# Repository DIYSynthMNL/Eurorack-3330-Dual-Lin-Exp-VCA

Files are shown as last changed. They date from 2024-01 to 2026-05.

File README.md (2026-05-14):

# Eurorack-3330-Dual-Lin-Exp-VCA

A Eurorack dual VCA based on the [AS3330](https://electricdruid.net/product/as3330-vca/) chip — two independent voltage-controlled amplifiers in one PDIP-18 package, each with simultaneous linear and exponential control inputs. Wide control range (120 dB), low distortion (<0.1%), low feedthrough (<−90 dB).

This design adds a **Lin/Exp blend knob per channel** (smooth pan between linear and exponential response), a **CV attenuator + offset** for shaping the control signal, an **LED level indicator**, and a **mix output** that sums both VCAs.

## Features

- **Two independent VCAs** in one chip (AS3330 PDIP-18)
- **Per-channel Lin/Exp blend** — one knob smoothly mixes linear and exponential CV response
- **CV attenuator + offset** per channel — handles ±5V, 0–5V, or 0–10V CV ranges
- **Mix output** (Sig 1 + Sig 2 summed via U5A/U5B)
- **Output-2 select jumper (JP1)** — Sig 2 jack outputs either VCA2 directly or the Mix
- **Bipolar LED indicator** per channel — shows CV level
- Eurorack ±12V power via either 16-pin IDC or 3-pin JST connector
- Local −5V reference rail (`-5VREF`) generated by a TL072-based reference for CV scaling

## Inputs and outputs

| Jack | Range | Notes |
|---|---|---|
| Sig In 1 | 10 Vpp (±5V) | Through 100K (Rl) to chip pin 4 IN1 |
| Sig In 2 | 10 Vpp (±5V) | Through 100K (Rl) to chip pin 13 IN2 |
| CV1 In | ±5V / 0–5V / 0–10V | Routed through CV scaling section (atten + offset + Lin/Exp blend) |
| CV2 In | ±5V / 0–5V / 0–10V | Same |
| Sig Out 1 | 10 Vpp (±5V) | Transimpedance buffer with R5 (100K) feedback |
| Sig Out 2 / Mix Out | 10 Vpp | JP1 selects between Sig Out 2 alone or the Mix Out (sum of both VCAs) |

Front-panel pots (per channel):

| Pot | Value | Function |
|---|---|---|
| RV1 / RV4 | 100K | **CV Attenuation** — scales the CV jack signal |
| RV3 / RV6 | 10K | **CV Offset** — adds a manual offset (−5V to +5V via −5V_REF) |
| RV2 / RV5 | 10K | **Lin/Exp blend** — fully left = pure linear response, fully right = pure exponential |

Internal trim:

| Trim | Value | Function |
|---|---|---|
| RV7 | 10K | Sets the −5V_REF level (TL072 reference generator) |

## Block diagram (per channel)

```
CV in ──[RV1 100K atten]──┐
                          ▼
−5V_REF ──[RV3 10K offset]──┐
                            ▼
                       [TL074 inverting summer + LED driver]
                            │
                            ▼
                       [RV2 10K Lin/Exp blend pot]
                       ├── (left tap) ──► [TL074 inverter + BAT42 clamp] ──► Linear CV (chip pin 7 / 12)
                       └── (right tap) ──► [TL074 offset + BAT42 clamp] ──► Exponential CV (chip pin 6 / 14)

Sig in ──[Rl 100K]──► AS3330 pin 4 IN1 / pin 13 IN2

AS3330:
  Pin 1 / 16 Out1/2 ──► [TL072 transimpedance, RF 100K] ──[1K series]──► Sig Out 1 / 2 jack
  Pin 2 / 15 VG1/2  ──[RB 120K to +12V]──► Iref = 100 µA (per datasheet's 100 µA design point)
                     [also 1nF compensation cap]
  Pin 3 / 17 DTrim1/2 ── GND (no distortion trim — see Design notes)
  Pin 6 / 14 VCE1/2  ──[Rce 33K + Ri 1K to GND, divider]──► from Exp CV path
  Pin 7 / 12 VCL1/2  ──[Rcl 100K]──► from Linear CV path
  Pin 8 IDLE         ──[Ridle 68K to +12V]── Class A bias
  Pin 5 VEE          ──[REE 560 Ω]── −12V
  Pin 9 / 11 CCOMP1/2 ──[5 nF to GND]── log-converter compensation
  Pin 10 VCC         ── +12V
  Pin 18 GND         ── GND

Mix Out: Sig Out 1 ──[R42 100K]──┐
         Sig Out 2 ──[R43 100K]──┴── U5A inverting summer ──[U5B unity inverter]── R41 1K ──► Mix Out
         (JP1 selects whether J10 = Sig Out 2 direct or Mix Out)
```

## Power

- Eurorack ±12V via **J8** (3-pin JST) or **J9** (16-pin IDC) — populate one
- D13 / D14: reverse-polarity protection
- C14 / C15 (22 µF): bulk rail decoupling
- C19 / C20 / C21 / C22 / C23 (100 nF) on each op-amp's supply pins
- C16 / C18 (100 nF) decoupling near AS3330 VCC / VEE pins
- **R48 = 560 Ω — AS3330 VEE current limiter** for −12V supply

REE formula (datasheet uses 680 Ω at ±15V):

| VEE supply | REE | I through REE |
|---|---|---|
| −15V | 680 Ω | ~13 mA (datasheet) |
| −12V | **560 Ω** ← *used here* | ~8.2 mA |
| −5V | none needed | (under threshold) |

Datasheet abs max for current into VEE pin is **±40 mA per pin** — both options well within spec.

**Local −5V reference (−5V_REF):** generated by a TL072 + RV7 (10K) network. This provides the negative half of the CV offset range. Trim RV7 to set −5V exactly (see Calibration).

## Calibration

This module has one internal trim (RV7) plus six front-panel pots per stereo pair (twelve total). Front-panel pots are runtime controls. Only RV7 is a true calibration trim.

**RV7 — −5V_REF trim.**
1. Power up the module and let it warm up 5 minutes.
2. Probe the −5VREF test point (TP1) or any other point on the −5V reference net.
3. Adjust RV7 until the reading is **−5.00 V** (or as close as a DMM allows).

Once −5V_REF is calibrated, both channels' CV offset behavior tracks correctly: with RV3/RV6 at minimum, the CV path is offset by −5V; at maximum, +5V; centered, 0V.

If the design adds **distortion trim pots** on chip pins 3 / 17 in a future revision (see [#issues](../../issues)), the calibration procedure would extend with a per-channel distortion null using a 1 kHz reference signal.

## Design notes

### Component-value choices vs the datasheet

This design tunes the AS3330's reference network for **±12V Eurorack supplies** rather than the datasheet's ±15V. The scaling preserves the datasheet's intended operating currents:

| Value | Datasheet (±15V) | This design (±12V) | Why |
|---|---|---|---|
| RB (Gain bias) | 150K to +15V → 100 µA | **120K to +12V → 100 µA** | Iref preserved for scale accuracy |
| REE (VEE limit) | 680 Ω → ~13 mA | **560 Ω → ~8 mA** | Same protection, lower power |
| Rcl (Lin series) | 100K | 100K | Unchanged |
| Rce (Exp series) | 33K + 1K | 33K + 1K | Unchanged |
| Ridle | 6.8K (datasheet example), 68K (Class A) | **68K — Class A** | Lower distortion, higher idle power |
| Ccomp | 5 nF | 5 nF | Unchanged |
| RF (transimpedance) | 51K → max gain 0.51× | **100K → max gain ~1×** | Match input level on output (10 Vpp in → 10 Vpp out) |

The `RF = 100K` choice deviates from the datasheet's 51K. Trade-off: for Eurorack ±5V signals, 100K gives unity gain at the output (input level = output level when CV is at max). The datasheet's 51K leaves more headroom — at max gain with full-scale signal, the chip's cell-current gain spec (up to 1.2×) means output could reach ~12V briefly. **At ±5V signal levels with 100K, no clipping in practice. Verify with a scope at max gain and full-scale input.**

### Deviations from the cited Digisound 80-9 reference

The README cites the Digisound 80-9 VCA3330 as a reference. Side-by-side, the two designs differ in five places worth knowing:

| Choice | This design | Digisound 80-9 | Comment |
|---|---|---|---|
| Distortion trim (pin 3 / 17) | GND | Trim pot via 5K + 100K | Digisound trims for low CV feedthrough; this design accepts untrimmed feedthrough (datasheet spec: ±5 µA in Class A) |
| Signal input AC coupling | DC | 330 nF AC coupling | Digisound is audio-only; this design accepts DC for CV-as-signal use |
| Signal input latch-up diode | None | 1N4148 to clamp | Digisound protects against >±6V transients on signal pin |
| RB (Gain bias) | 120K @ +12V → 100 µA | 100K @ +12V → 120 µA | Both work; this design hits the datasheet's 100 µA target exactly |
| Ridle | 68K (Class A) | 6.8K | Different distortion / power trade-off |
| CV control | Lin/Exp blend knob + offset + atten | Separate jacks for Lin / Exp / AM | Different design intent — performer vs studio |

## References

Local archived copies live in [`references/`](references/) so this repo stays useful if the upstream links die.

- **AS3330 datasheet** — [local copy](references/AS3330-alfatriode-2019.pdf) · [upstream (alfatriode.lv)](https://alfatriode.lv/eng/sc/AS3330.pdf)
- **Digisound 80-9 VCA3330 schematic** — [local copy](references/Digisound-80-9-VCA3330-schematic.pdf) · [upstream](https://electro-music.com/forum/phpbb-files/203_006_vca3330_schematic_119.pdf)
- [Digisound 80-9 module page](http://www.digisound80.co.uk/digisound/modules/80-9.htm) (calibration / theory)
- [Electric Druid AS3330 product page](https://electricdruid.net/product/as3330-vca/)
- [Geofex panner article](http://www.geofex.com/Article_Folders/panner.pdf) — useful theory for CV-controlled gain math
- [LT AN148 — log/antilog amp app note](https://www.analog.com/media/en/technical-documentation/application-notes/an148fa.pdf) — chip-internal log converter background
- Design inspiration: Intellijel's Quad VCA module (lin/exp response, CV offset)

## Build status

What's ready for builders today, and what's still on the TODO list:

**Production assets** (what you need to actually fabricate and assemble a final unit)

- [x] Schematic — Rev 0.1.7 ([AS3330-Dual-Linear-Exponential-VCA-Schematic-Rev0.1.7.pdf](Schematic%20PDFs/AS3330-Dual-Linear-Exponential-VCA-Schematic-Rev0.1.7.pdf))
- [ ] PCB layout — in progress — single working layout in `kicad/`, not yet separated for fab
- [ ] Gerber files for fabrication — none yet
- [ ] BOM — none yet
- [ ] Final front panel (SVG/PDF for fab) — none yet
- [ ] License — none yet

**Prototype assets** (for breadboard / perfboard / 3D-printed-panel builds before final PCB)

- [x] 3D-printed prototype panel STL — [3330_VCA.stl](3D%20Printed%20Panel/3330_VCA.stl)
- [x] Falstad simulations — [falstad/](falstad/)

**Documentation**

- [ ] Photos of the assembled module — none yet (drop in [`photos/`](photos/))
- [ ] Demo video — none yet
- [ ] Build / assembly instructions — none yet
- [x] Calibration notes — see Calibration section above

Want to help fill a gap (build photos, gerbers, an assembly guide)? Open an issue or PR.

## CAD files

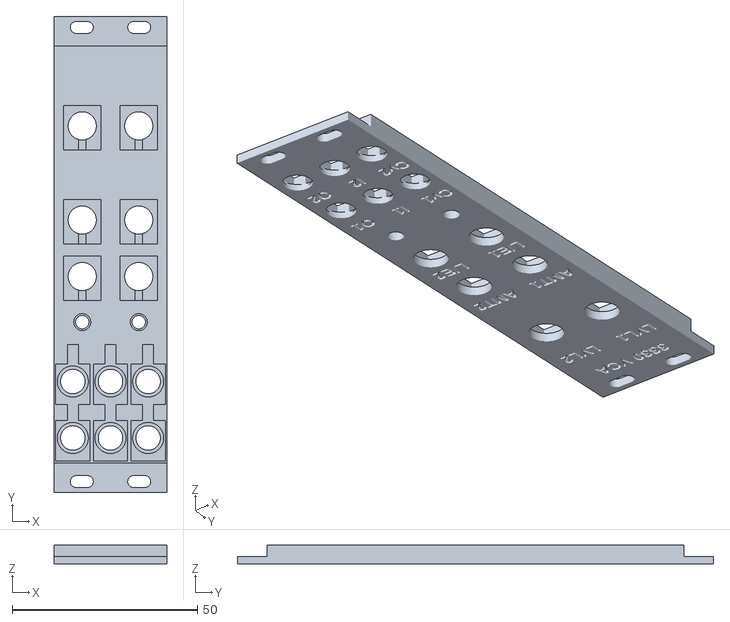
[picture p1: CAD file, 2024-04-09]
3D Printed Panel/3330_VCA.stl
30.5 x 128.5 x 5.00

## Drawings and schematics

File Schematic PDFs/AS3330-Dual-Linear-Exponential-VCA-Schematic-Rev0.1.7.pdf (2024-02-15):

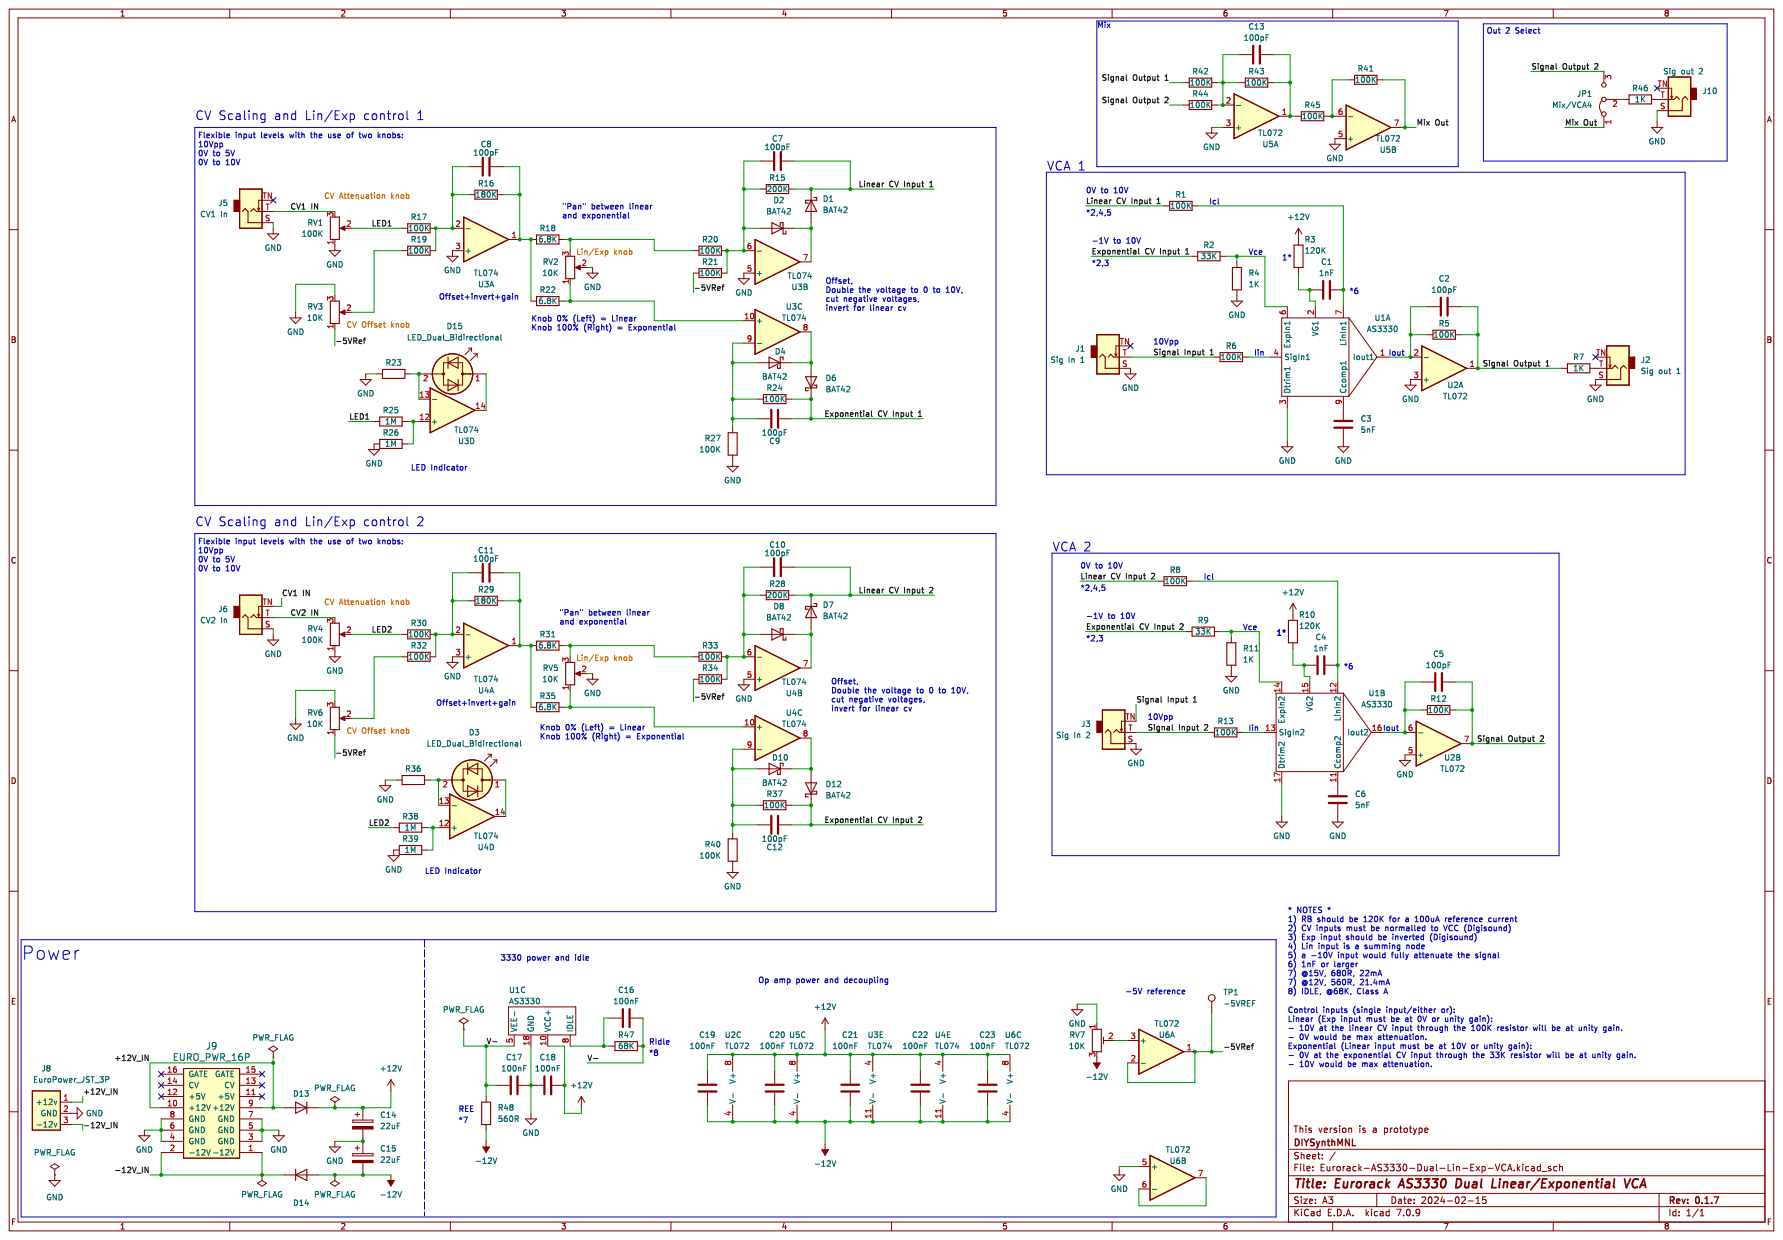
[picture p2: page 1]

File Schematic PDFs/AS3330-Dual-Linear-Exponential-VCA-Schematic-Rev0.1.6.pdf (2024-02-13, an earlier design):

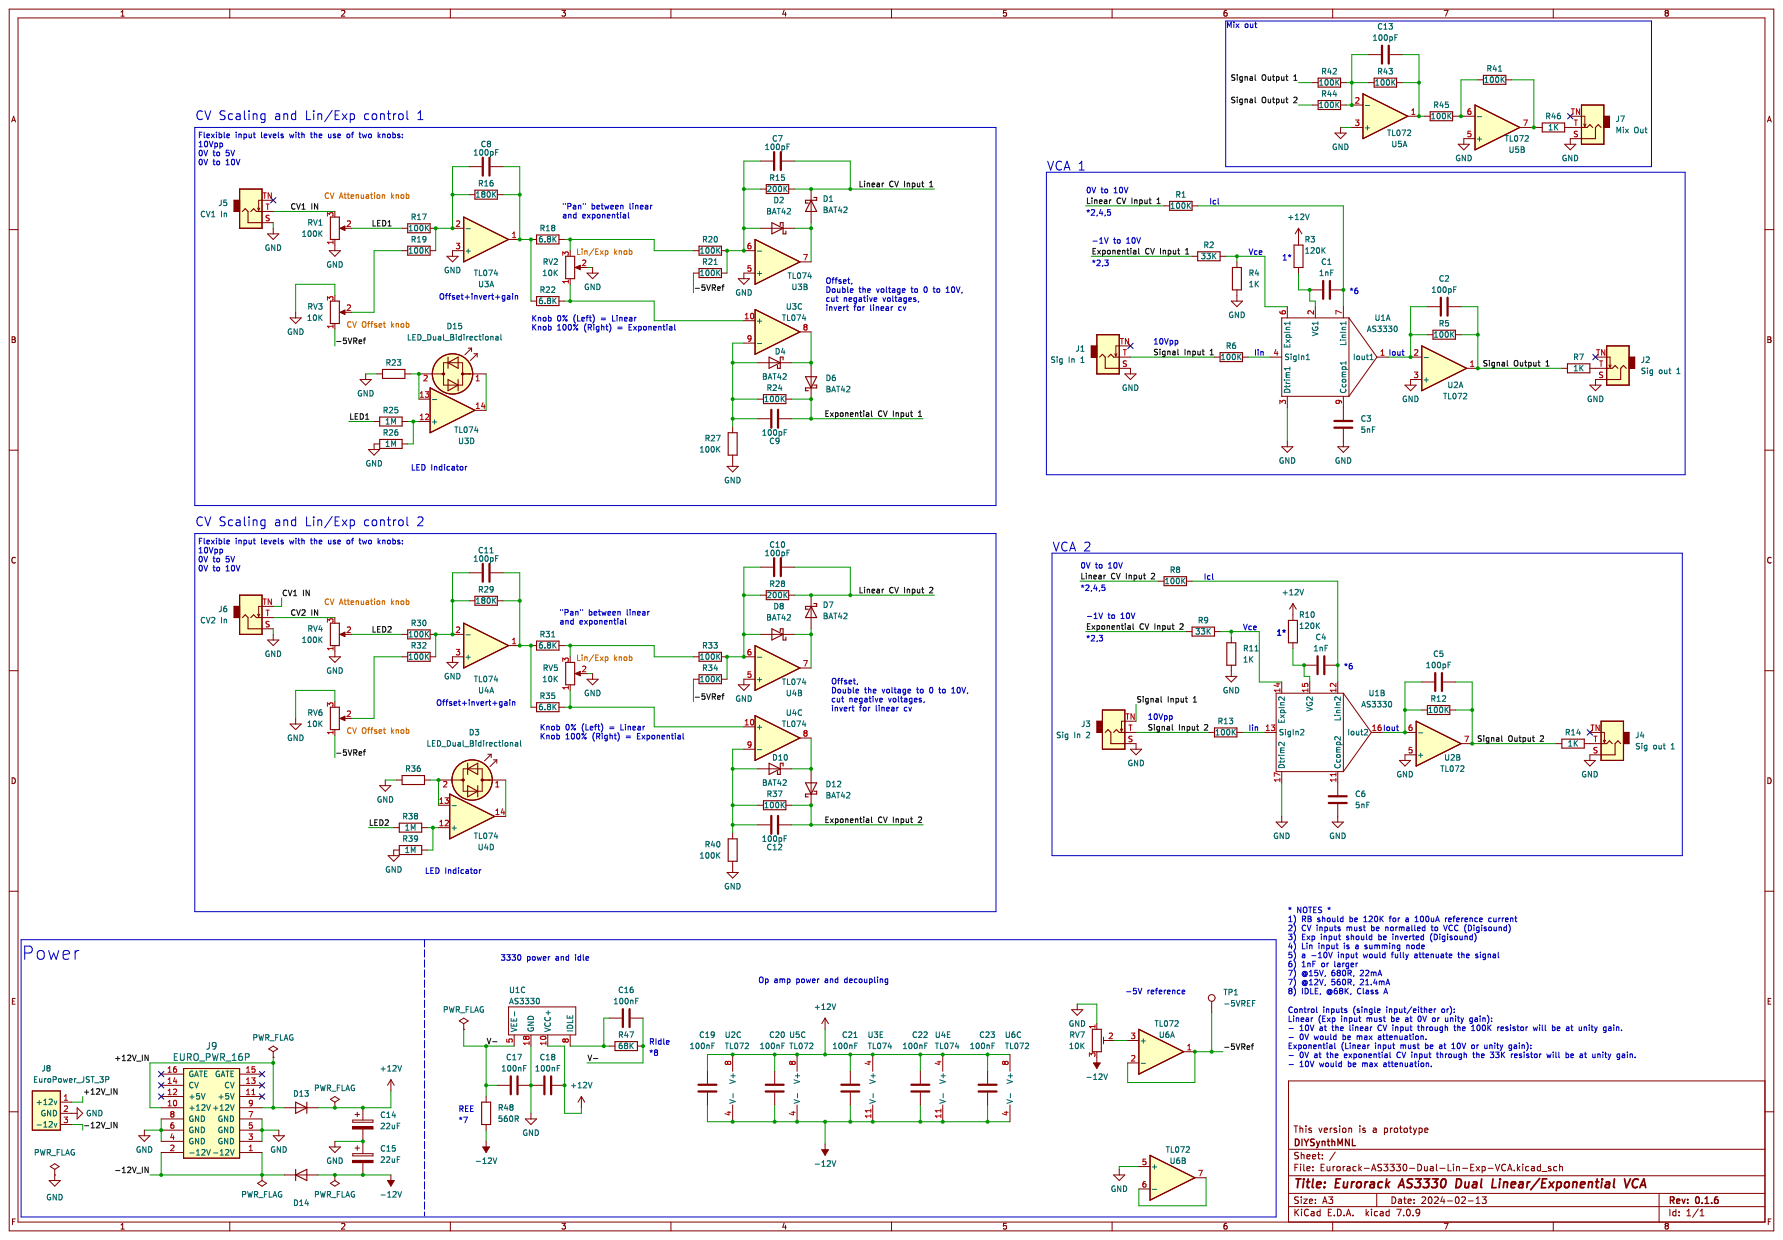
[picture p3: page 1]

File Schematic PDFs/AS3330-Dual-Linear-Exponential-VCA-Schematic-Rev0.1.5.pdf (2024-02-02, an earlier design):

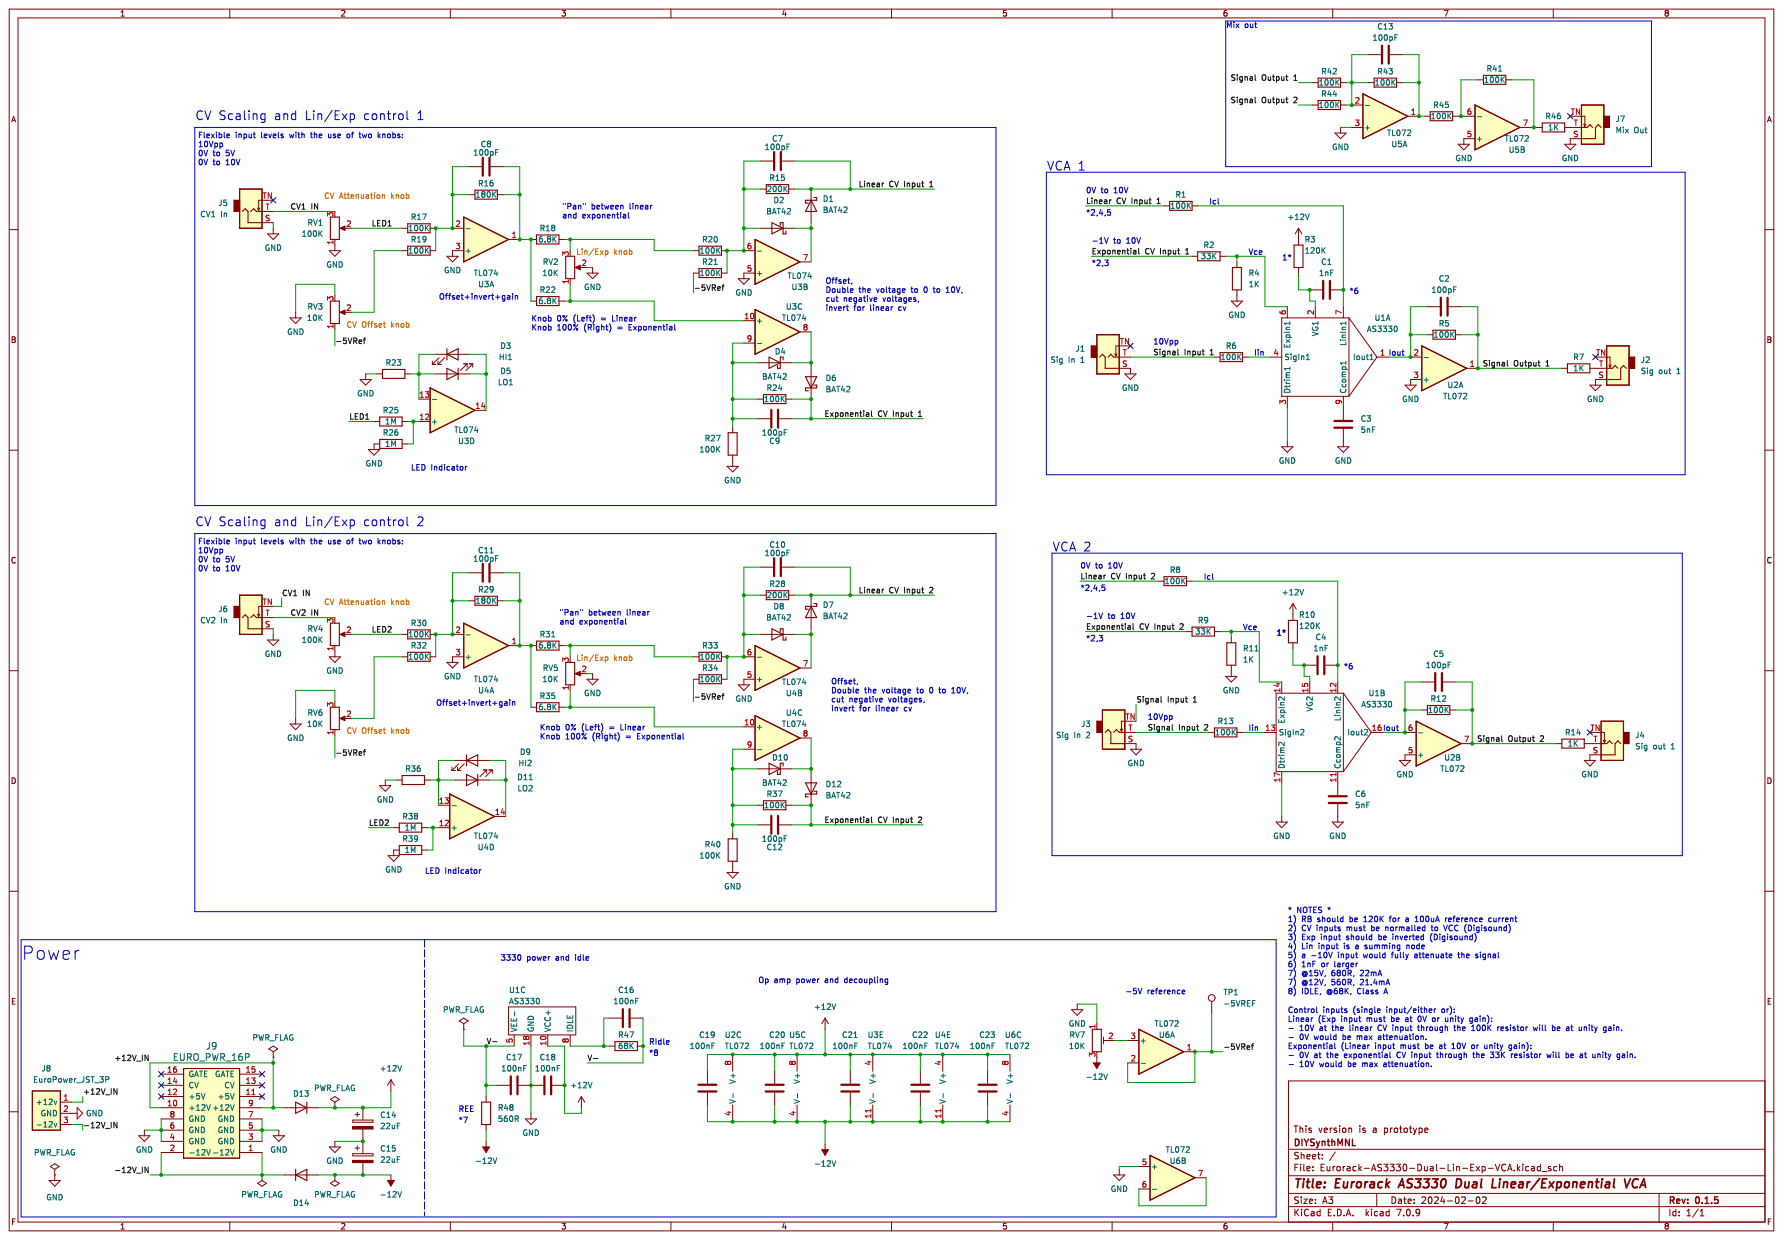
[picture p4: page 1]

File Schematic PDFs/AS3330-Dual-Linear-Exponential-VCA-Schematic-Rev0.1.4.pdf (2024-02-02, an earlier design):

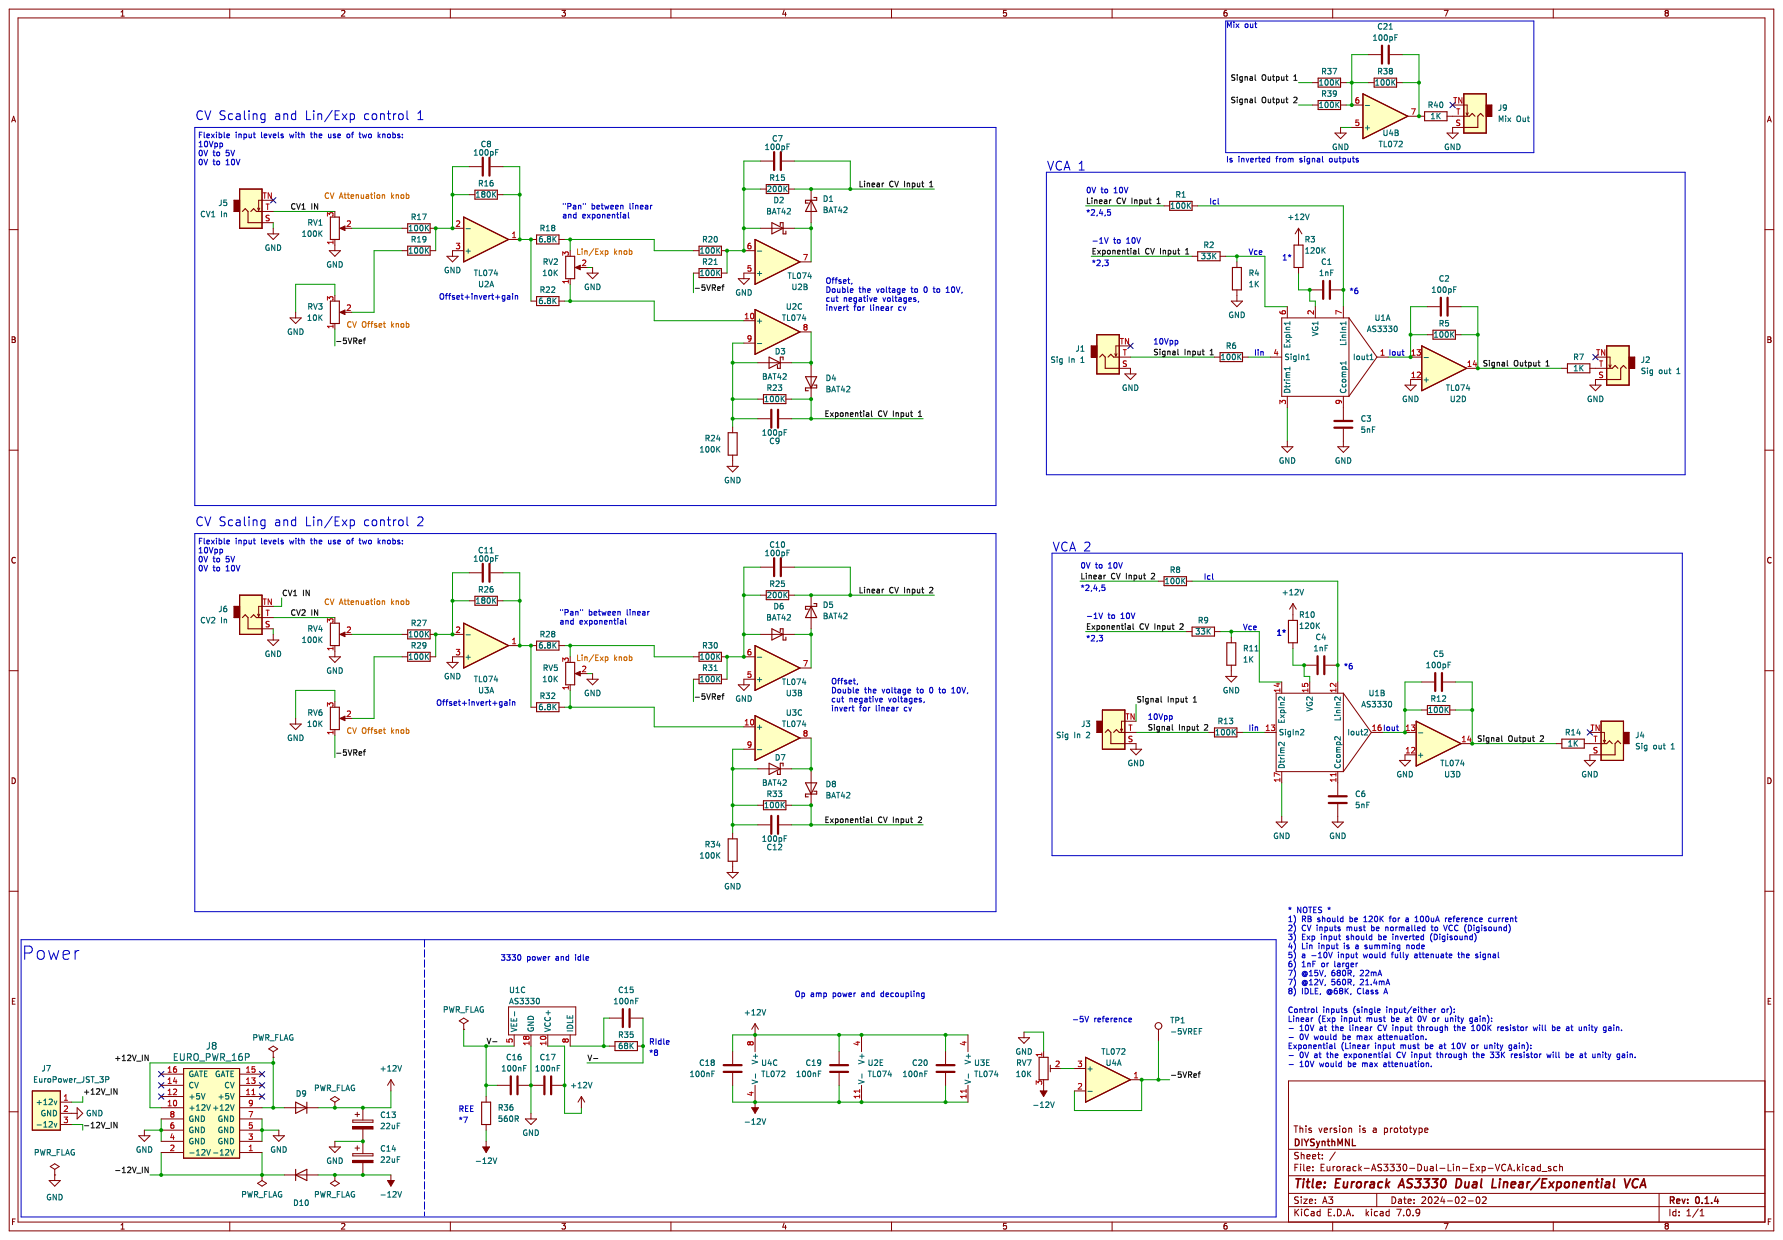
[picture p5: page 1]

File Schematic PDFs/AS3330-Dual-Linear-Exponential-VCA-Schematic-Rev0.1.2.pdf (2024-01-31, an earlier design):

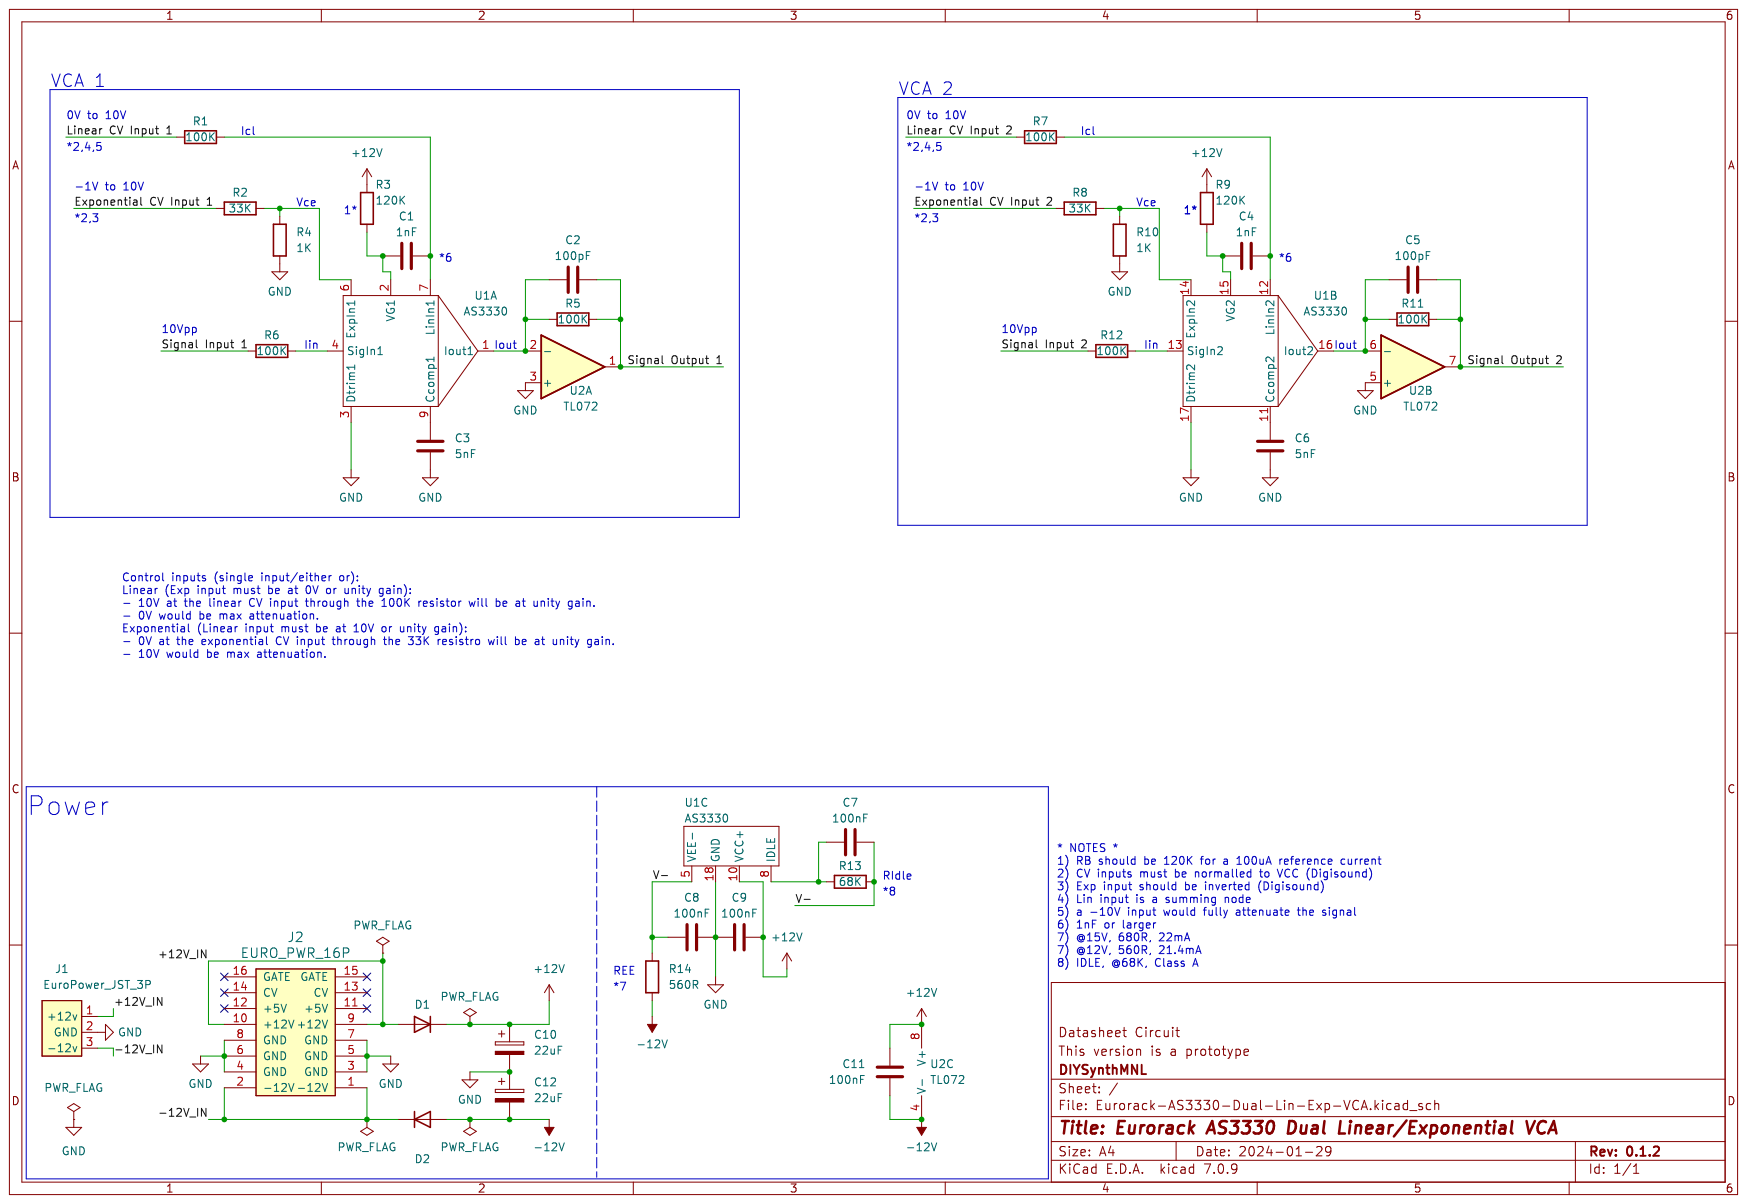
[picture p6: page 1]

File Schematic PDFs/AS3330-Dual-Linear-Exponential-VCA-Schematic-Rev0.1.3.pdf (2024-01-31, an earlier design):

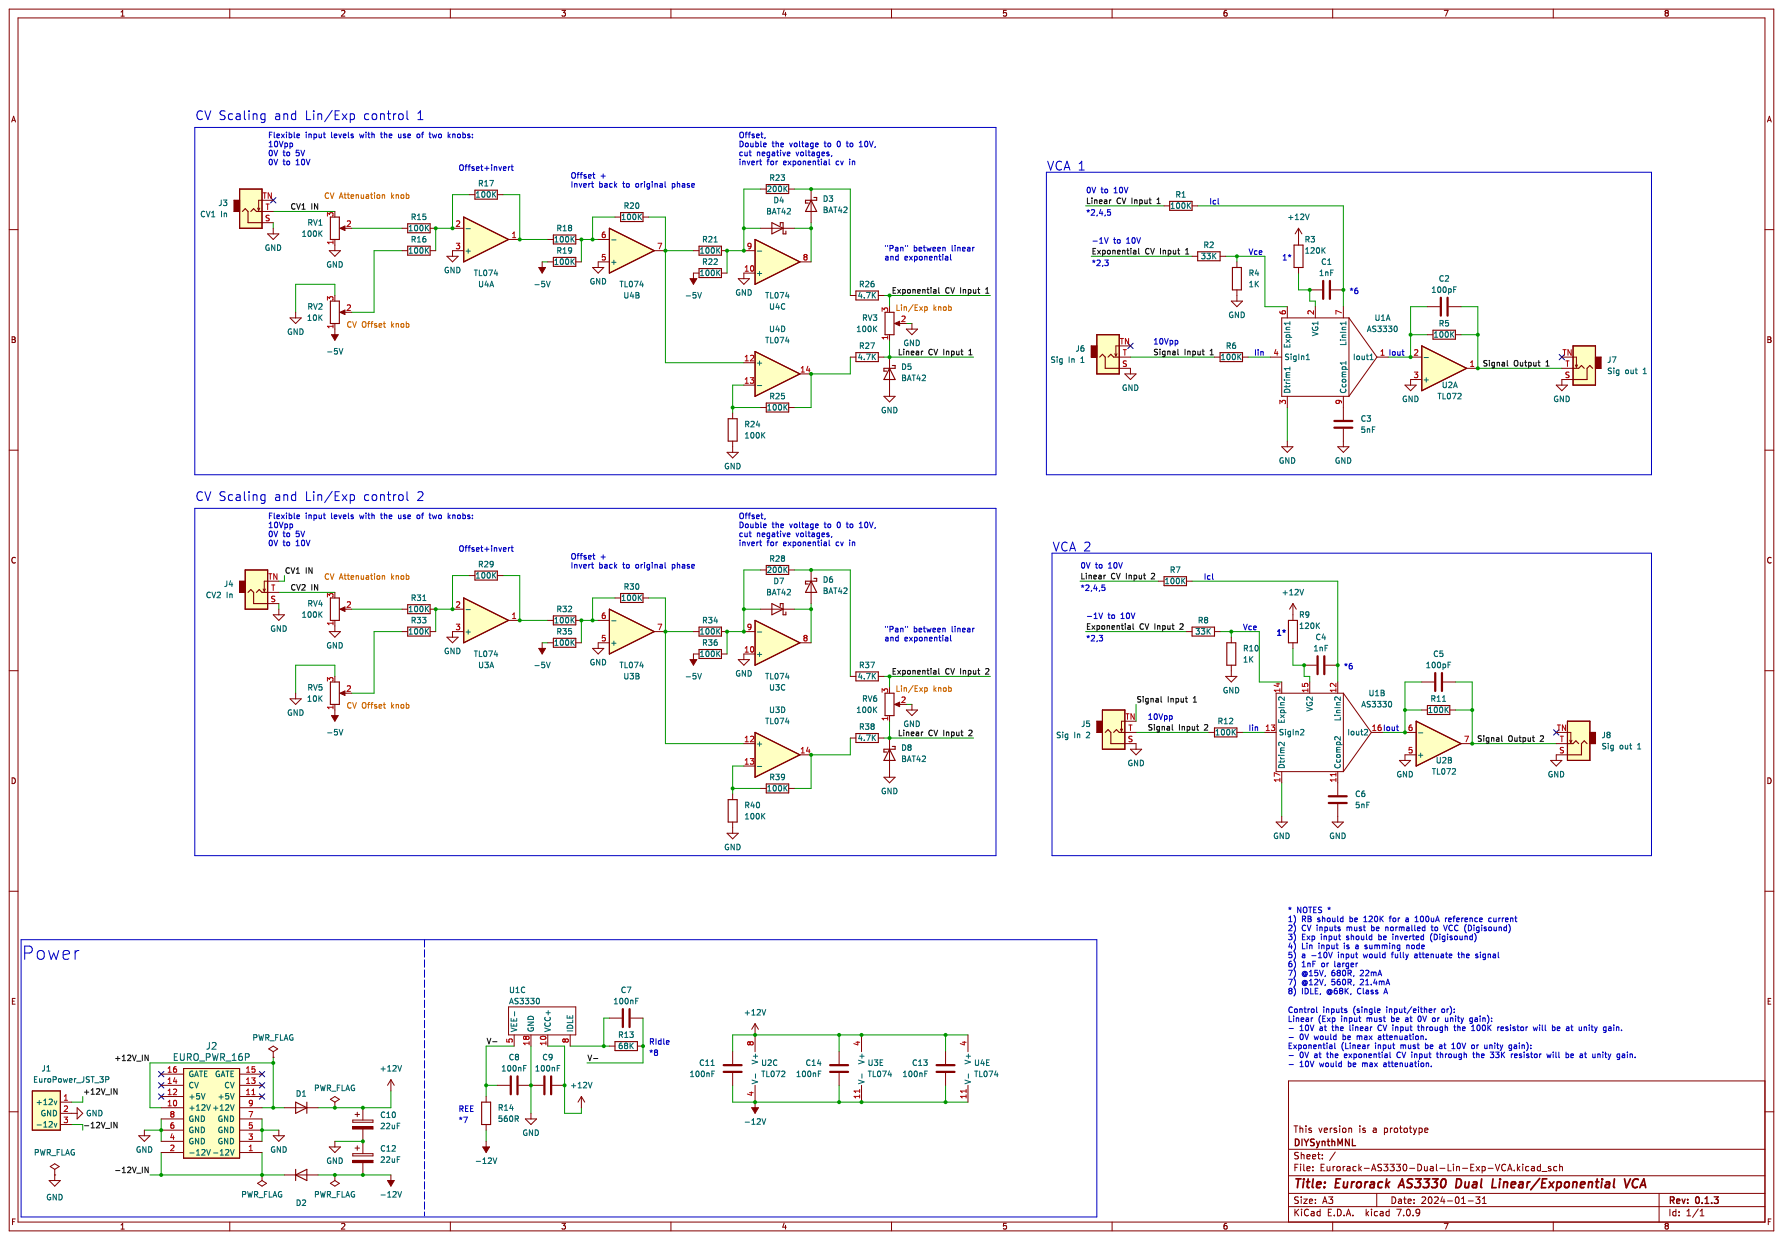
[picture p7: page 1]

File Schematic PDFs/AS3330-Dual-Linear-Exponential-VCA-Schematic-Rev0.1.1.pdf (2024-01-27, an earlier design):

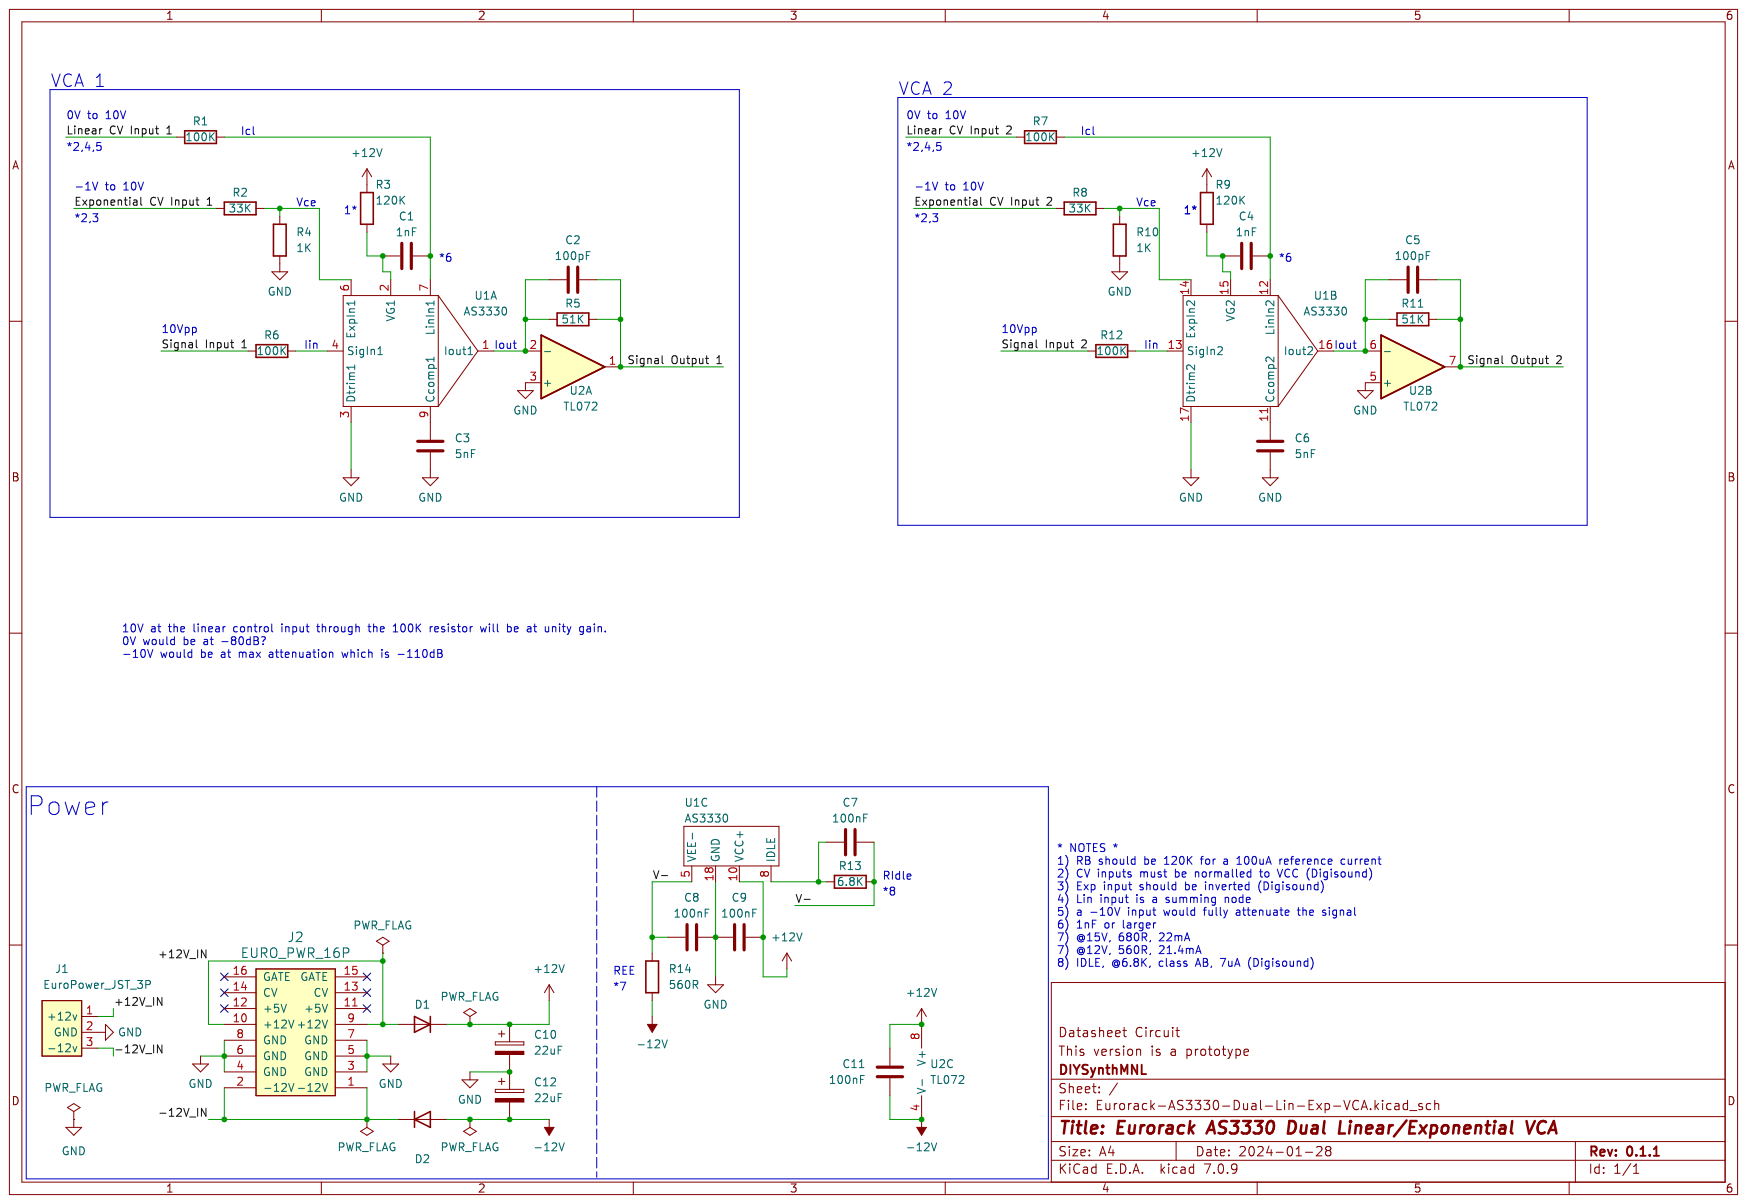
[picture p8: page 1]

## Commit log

2024-01-27 datasheet circuit drawn
    [Eurorack-AS3330-Dual-Lin-Exp-VCA.kicad_pcb, Eurorack-AS3330-Dual-Lin-Exp-VCA.kicad_sch]
2024-01-27 Added Schematic revision 0.1.1
    [Eurorack-AS3330-Dual-Lin-Exp-VCA.kicad_sch]
2024-01-27 updated schematic rev 0.1.1
    [Eurorack-AS3330-Dual-Lin-Exp-VCA.kicad_sch]
2024-01-31 added schematic revision 0.1.3
    [Eurorack-AS3330-Dual-Lin-Exp-VCA.kicad_sch]
2024-02-02 Added Schematic revision 0.1.4
    [Eurorack-AS3330-Dual-Lin-Exp-VCA.kicad_sch]
2024-02-02 added schematic rev0.1.5
    [Eurorack-AS3330-Dual-Lin-Exp-VCA.kicad_sch]
2024-02-02 Schematic rev 0.1.5 updated
    [Eurorack-AS3330-Dual-Lin-Exp-VCA.kicad_sch]
2024-02-13 Added schematic rev 0.1.6
    [Eurorack-AS3330-Dual-Lin-Exp-VCA.kicad_sch]
2024-02-15 added schem rev 0.1.7
    [Eurorack-AS3330-Dual-Lin-Exp-VCA.kicad_sch]
2026-05-14 Fix Build status link path case
2026-05-14 Add photos/ placeholder for assembled-module shots
2026-05-14 Deep-dive rewrite: README + references/ folder with AS3330 datasheet and Digisound 80-9 schematic
    Restructures the README to match the standard module layout
    (features, I/O table, block diagram, power, calibration, design notes,
    references, build status). Documents the Lin/Exp blend topology, the
    ±12V vs ±15V component-value scaling, and the deliberate departures
    from the cited Digisound 80-9 reference (RF = 100K, no distortion
    trim, Class A idle).
    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
